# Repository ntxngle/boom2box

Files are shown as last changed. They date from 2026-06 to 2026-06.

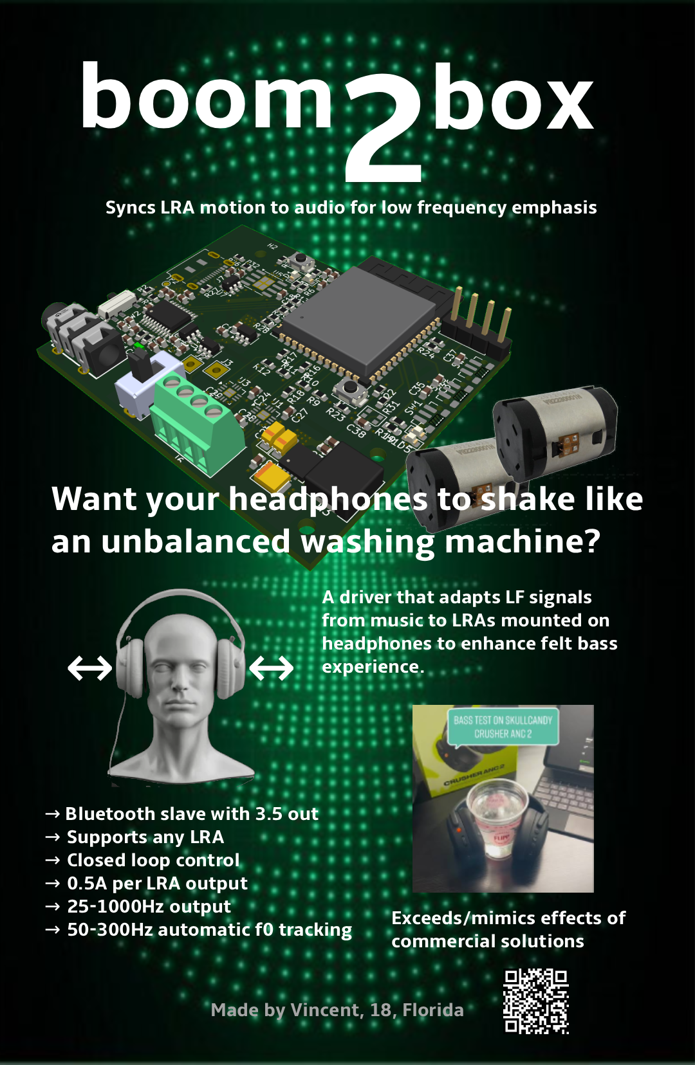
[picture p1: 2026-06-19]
docs/mzine.png

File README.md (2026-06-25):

# boom2box
## What and Why

A driver that adapts LF signals from music to LRAs mounted on headphones to enhance felt bass experience. It does this with a bunch of QoL features like leds, neopixel, switches, audio jack for lantency free experience.

In addition, the LRAs can be mounted to not only headphones: shaking a table or chair can also produce excellent results.

This is to replicate the feeling of having high power speakers which I can neither afford nor run. I always enjoy bass in music, and this project should hopefully replicate this experience at minimal cost (and minimal noise to peers). A few years ago a friend showed me his headphones and I was surprised to feel that they shook like crazy. This same geek blasted shadow money wizard gang at the crisp 6AM on the bus, so I figure he must know his music. Fast forward to a few months ago, I put some terribly old desktop speakers on my desk and spent very valuable time (in lieu of studying for linear: I now have an F) on maximizing bass output. Obviously to my disappointment I didn't feel the chest thumping explosions found only in brazilian car modifier demonstrations, it did vibrate my desk a little in the right conditions. A suprisingingly bass-like experience. Thus, after finishing my other fallout project, I set out to replicate that feeling in the most intense way. While i couldn't mount double digit diameter subwoofers in my obviously homework filled drawers, I figured I could cheat by generating the vibrations directly.

## Tuff photos

Since the project isn't tuff I don't have tuff photos. Here are some unrelated photos.








## How it works
A DSP grabs low end of incoming audio, does some normalization (or not) and sends waveform to LRA driver.

These LRA drivers are the jewel of the project: automatic f_0 tracking, closed loop, etc etc read the zine. They are the ones responsible for driving the huge 15$ 3.5G thumpers that I plan to connect to them: another versatility of this project is that other LRAs work. Anything from 10mm aliexpress buzzers to massive rectangular theater grade shakers (3Vrms, 1/2 amp max) will work identically (other than f0: DSP should be retuned to pitch bass up or down closer to f0 for maximum amplitude.

To avoid delay between audio and motion, a headphone jack is included. This way I can control audio out to motion, to solve potential (and variable) desyncs. It also makes for a great way to turn wired over-ears (the target of this project) into wireless skull shakers.

## BOM
|name |quantity|cost |link |
|---|---|-----|---|
|PCB |1 |76.32|gerbers in this repo |
|LRA VG2230001H |2 |15.66|https://www.digikey.com/en/products/detail/vybronics-inc/VG2230001H/16719289|
|1c LiPo >500mAh|1 |5 |tear one out of genuinely anything |
|Case |1 |~2 |Simple ahh 3d printed case costs like 10 cents in filament |
|total |1 |98.98| |

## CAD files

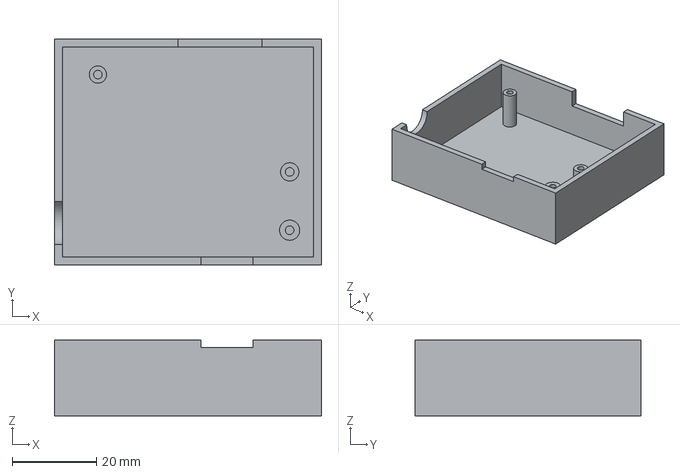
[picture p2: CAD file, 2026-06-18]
mechanical/case.step
63.5 x 53.8 x 18.0 mm

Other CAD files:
mechanical/case.FCStd

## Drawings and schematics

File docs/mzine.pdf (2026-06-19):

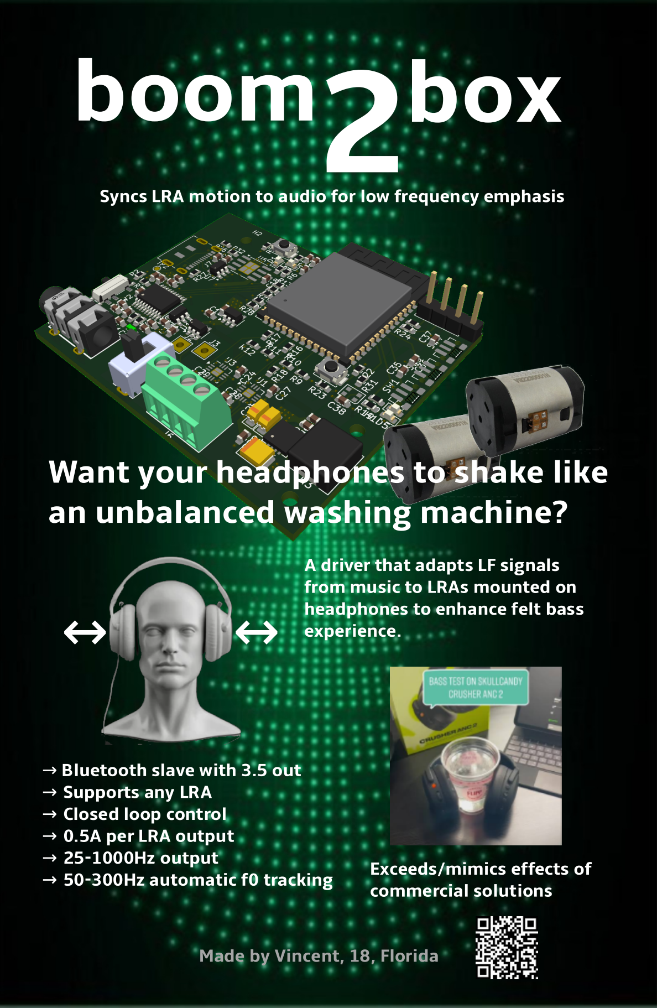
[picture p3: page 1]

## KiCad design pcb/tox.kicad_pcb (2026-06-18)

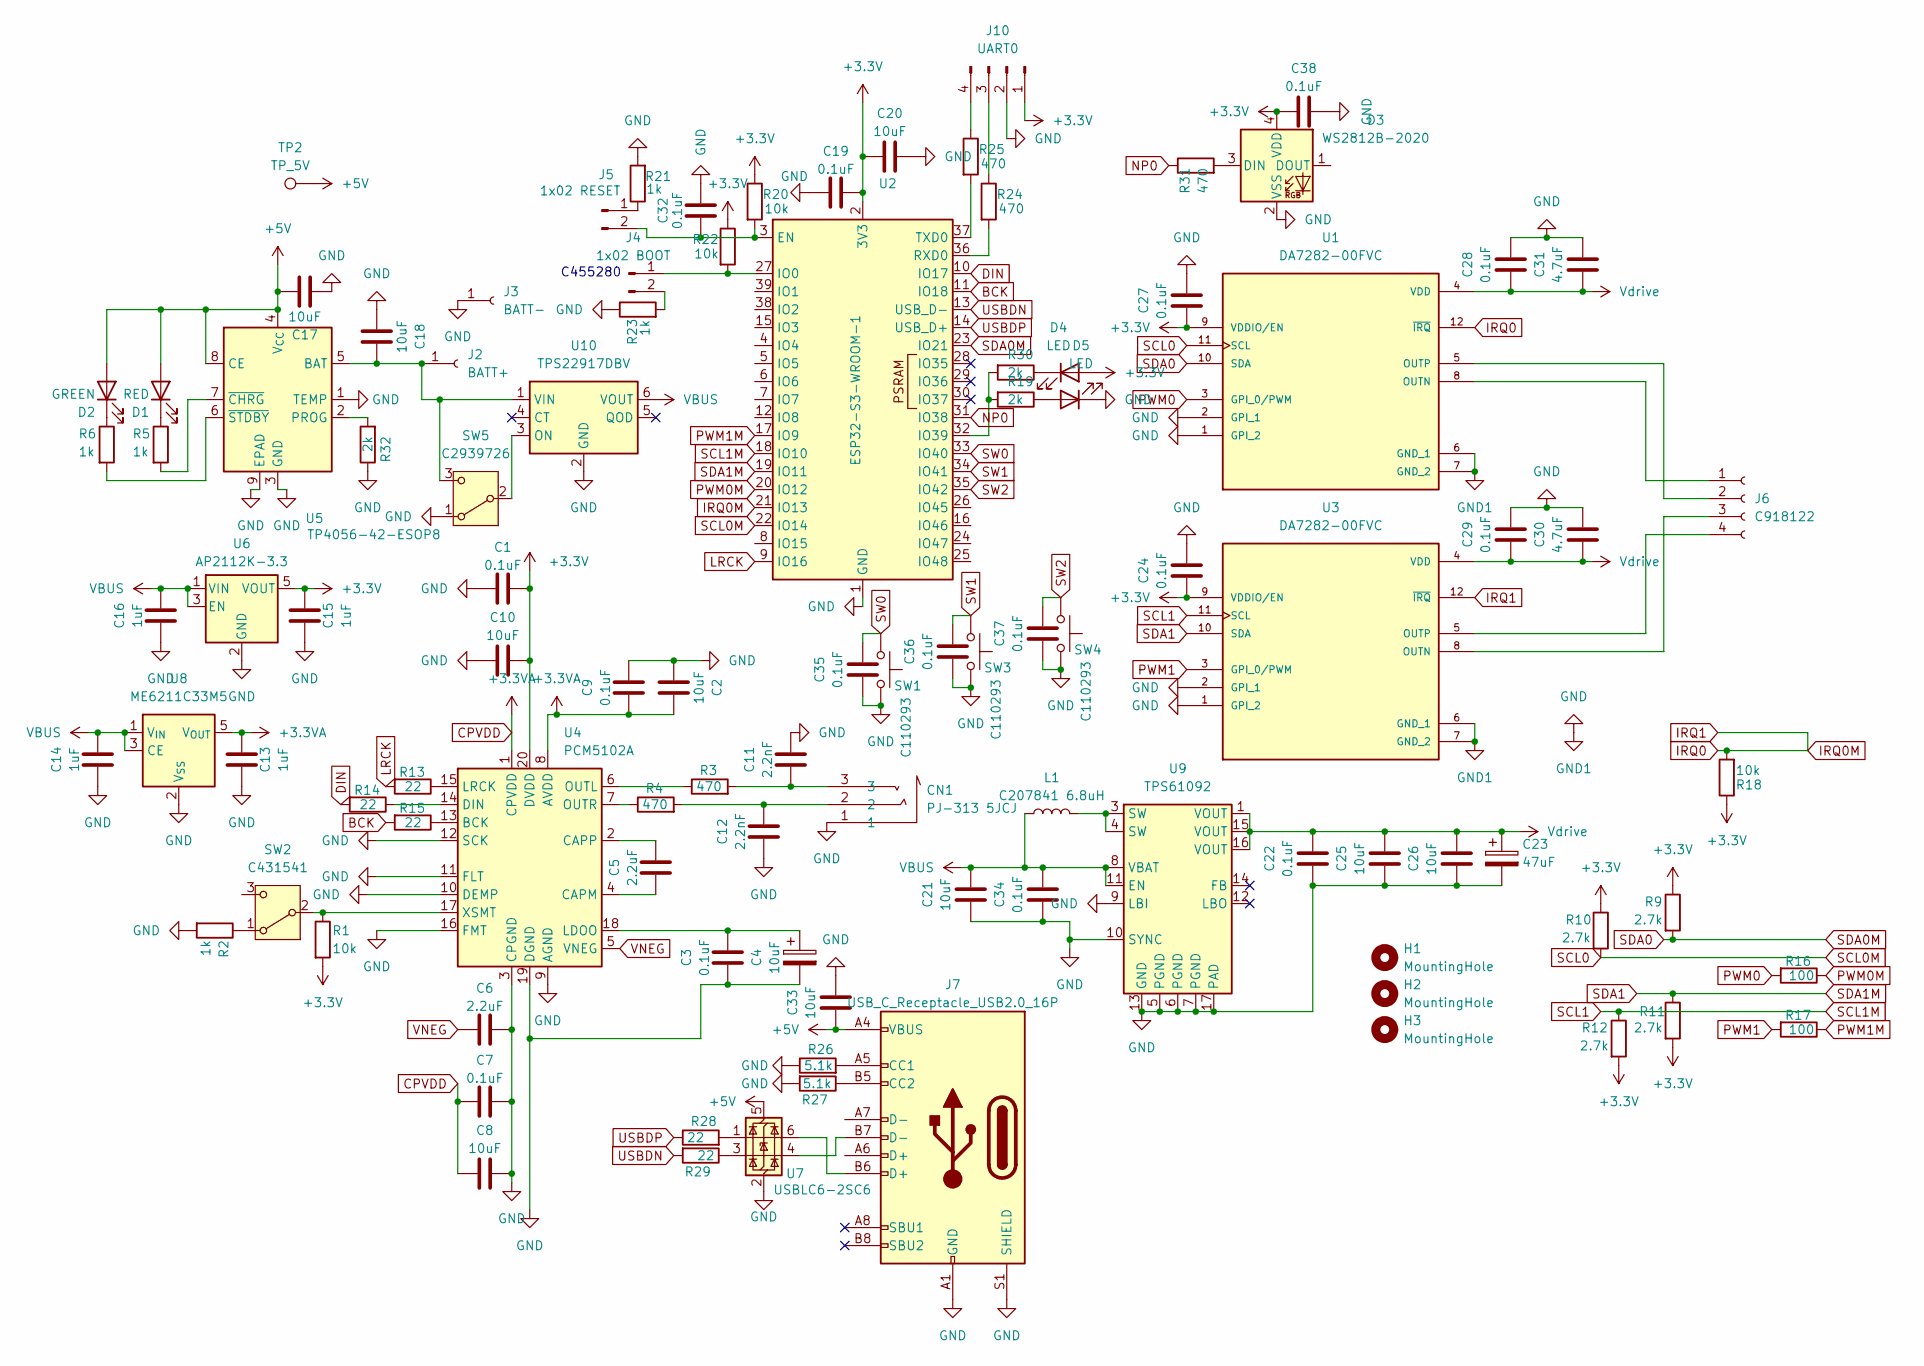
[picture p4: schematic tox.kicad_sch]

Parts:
C1, C3, C7, C9, C19, C22, C24, C27, C28, C29, C32, C34, C35, C36, C37, C38: 0.1uF; C_0603_1608Metric
C2, C4, C8, C10, C17, C18, C20, C21, C33: 10uF; C_0603_1608Metric
C5, C6: 2.2uF; C_0603_1608Metric
C11, C12: 2.2nF; C_0603_1608Metric
C13, C14, C15, C16: 1uF; C_0603_1608Metric
C23: 47uF; CP_EIA-3528-12_Kemet-T
C25, C26: 10uF; CP_EIA-3216-18_Kemet-A
C30, C31: 4.7uF; C_0603_1608Metric
CN1: PJ-313 5JCJ; AUDIO-TH_PJ-313_5JCJ; MPN PJ-313 5JCJ; LCSC Part C668607
D1: RED; LED_0603_1608Metric
D2: GREEN; LED_0603_1608Metric
D3: WS2812B-2020; LED_WS2812B-2020_PLCC4_2.0x2.0mm
D4, D5: LED; LED_0603_1608Metric
H1, H2, H3: MountingHole; MountingHole_2.1mm
J2: BATT+; TestPoint_THTPad_2.5x2.5mm_Drill1.2mm
J3: BATT-; TestPoint_THTPad_2.5x2.5mm_Drill1.2mm
J4: 1x02 BOOT; SW_Push_SPST_NO_Alps_SKRK
J5: 1x02 RESET; SW_Push_SPST_NO_Alps_SKRK
J6: C918122; CONN-TH_DB125-2.54-4P-GN
J7: USB_C_Receptacle_USB2.0_16P; USB_C_Receptacle_JAE_DX07S016JA1R1500
J10: UART0; PinHeader_1x04_P2.54mm_Vertical
L1: C207841 6.8uH; L_AVX_LMLP07A7
R1, R18, R20, R22: 10k; R_0603_1608Metric
R2, R5, R6, R21, R23: 1k; R_0603_1608Metric
R3, R4, R24, R25, R31: 470; R_0603_1608Metric
R9, R10, R11, R12: 2.7k; R_0603_1608Metric
R13, R14, R15, R28, R29: 22; R_0603_1608Metric
R16, R17: 100; R_0603_1608Metric
R19, R30, R32: 2k; R_0603_1608Metric
R26, R27: 5.1k; R_0603_1608Metric
SW1, SW3, SW4: C110293; SW_Push_1P1T-MP_NO_Horizontal_Alps_SKRTLAE010
SW2: C431541; SW_SPDT_PCM12
SW5: C2939726; SW_SS12D07VG4
TP2: TP_5V; TestPoint_Pad_D1.0mm
U1, U3: DA7282-00FVC; QFN-12-1EP_3x3mm_P0.5mm_EP1.45x1.45mm; PARTREV 3.1
U2: ESP32-S3-WROOM-1
U4: PCM5102A; TSSOP-20_4.4x6.5mm_P0.65mm
U5: TP4056-42-ESOP8; SOIC-8-1EP_3.9x4.9mm_P1.27mm_EP2.41x3.3mm
U6: AP2112K-3.3; SOT-23-5
U7: USBLC6-2SC6; SOT-23-6
U8: ME6211C33M5; SOT-23-5
U9: TPS61092; Texas_RSA_VQFN-16-1EP_4x4mm_P0.65mm_EP2.7x2.7mm
U10: TPS22917DBV; SOT-23-6

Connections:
+3.3V: C1.2, C10.1, C15.1, C19.2, C20.2, C24.2, C27.2, C38.2, D3.4 (VDD), D4.2 (A), J10.1, R1.2, R9.1, R10.1, R11.2, R12.2, R18.1, R20.1, R22.1, U1.9 (VDDIO/EN), U2.2 (3V3), U3.9 (VDDIO/EN), U4.20 (DVDD), U6.5 (VOUT)
+5V: C17.1, C33.2, D1.2 (A), D2.2 (A), J7.A4 (VBUS), J7.A9 (VBUS), J7.B4 (VBUS), J7.B9 (VBUS), TP2.1, U5.4 (V_{CC}), U5.8 (CE), U7.5 (VBUS)
BCK: R15.2, U2.11 (IO18)
CPVDD: C2.1, C7.1, C8.2, C9.1, C13.1, U4.1 (CPVDD), U4.8 (AVDD), U8.5 (V_{OUT})
DIN: R14.2, U2.10 (IO17)
GND: C1.1, C2.2, C3.1, C4.2, C6.2, C7.2, C8.1, C9.2, C10.2, C11.2, C12.1, C13.2, C14.1, C15.2, C16.1, C17.2, C18.2, C19.1, C20.1, C21.2, C22.2, C23.2, C24.1, C25.2, C26.2, C27.1, C28.1, C29.1, C30.1, C31.1, C32.2, C33.1, C34.2, C35.2, C36.2, C37.2, C38.1, CN1.1, D3.2 (VSS), D5.1 (K), J3.1, J7.A1 (GND), J7.A12 (GND), J7.B1 (GND), J7.B12 (GND), J7.S1 (SHIELD), J10.2, R2.2, R21.2, R23.1, R26.1, R27.2, R32.1, SW1.2, SW3.2, SW4.2, SW5.1 (A), U1.1 (GPI_2), U1.2 (GPI_1), U1.6 (GND_1), U1.7 (GND_2), U2.1 (GND), U2.40 (GND), U2.41 (GND), U3.1 (GPI_2), U3.2 (GPI_1), U3.6 (GND_1), U3.7 (GND_2), U4.3 (CPGND), U4.9 (AGND), U4.10 (DEMP), U4.11 (FLT), U4.12 (SCK), U4.16 (FMT), U4.19 (DGND), U5.1 (TEMP), U5.3 (GND), U5.9 (EPAD), U6.2 (GND), U7.2 (GND), U8.2 (V_{SS}), U9.5 (PGND), U9.6 (PGND), U9.7 (PGND), U9.9 (LBI), U9.10 (SYNC), U9.13 (GND), U9.17 (PAD), U10.2 (GND); also elsewhere on the board
IRQ0: R18.2, U1.12 (~IRQ), U2.21 (IO13), U3.12 (~IRQ)
LRCK: R13.2, U2.9 (IO16)
NP0: R31.1, U2.31 (IO38)
unnamed: C11.1, CN1.3, R3.2
unnamed: C12.2, CN1.2, R4.2
unnamed: D1.1 (K), R5.1
unnamed: D2.1 (K), R6.1
unnamed: D3.3 (DIN), R31.2
unnamed: D4.1 (K), R30.1
unnamed: D5.2 (A), R19.1
unnamed 16: C18.1, J2.1, SW5.3 (C), U5.5 (BAT), U10.1 (VIN); also elsewhere on the board
unnamed: J4.1, R22.2, U2.27 (IO0)
unnamed: J4.2, R23.2
unnamed: J5.1, R21.1
unnamed: C32.1, J5.2, R20.2, U2.3 (EN)
unnamed: J6.1, U1.8 (OUTN)
unnamed: J6.2, U1.5 (OUTP)
unnamed: J6.3, U3.8 (OUTN)
unnamed: J6.4, U3.5 (OUTP)
unnamed: J7.A5 (CC1), R26.2
unnamed: J7.B5 (CC2), R27.1
unnamed: J7.B6 (D+), U7.6 (I/O1)
unnamed: J7.B7 (D-), U7.4 (I/O2)
unnamed: J10.3, R24.1
unnamed: J10.4, R25.1
unnamed: L1.2, U9.3 (SW), U9.4 (SW)
unnamed: R28.2, U7.1 (I/O1)
unnamed: R29.1, U7.3 (I/O2)
unnamed: R2.1, SW2.1 (A)
unnamed: R1.1, SW2.2 (B), U4.17 (XSMT)
unnamed: SW5.2 (B), U10.3 (ON)
unnamed: R19.2, R30.2, U2.32 (IO39)
unnamed: R24.2, U2.36 (RXD0)
unnamed: R25.2, U2.37 (TXD0)
unnamed: R15.1, U4.13 (BCK)
unnamed: C5.1, U4.4 (CAPM)
unnamed: C5.2, U4.2 (CAPP)
unnamed: R14.1, U4.14 (DIN)
unnamed: C3.2, C4.1, U4.18 (LDOO)
unnamed: R13.1, U4.15 (LRCK)
unnamed: R3.1, U4.6 (OUTL)
unnamed: R4.1, U4.7 (OUTR)
unnamed: R32.2, U5.2 (PROG)
unnamed: R5.2, U5.7 (~CHRG)
unnamed: R6.2, U5.6 (~STDBY)
PWM0: R16.2, U1.3 (GPI_0/PWM)
PWM0M: R16.1, U2.20 (IO12)
PWM1: R17.2, U3.3 (GPI_0/PWM)
PWM1M: R17.1, U2.17 (IO9)
SCL0: R10.2, U1.11 (SCL), U2.22 (IO14)
SCL1: R12.1, U2.18 (IO10), U3.11 (SCL)
SDA0: R9.2, U1.10 (SDA), U2.23 (IO21)
SDA1: R11.1, U2.19 (IO11), U3.10 (SDA)
SW0: C35.1, SW1.1, U2.33 (IO40)
SW1: C36.1, SW3.1, U2.34 (IO41)
SW2: C37.1, SW4.1, U2.35 (IO42)
USBDN: R29.2, U2.13 (USB_D-)
USBDP: R28.1, U2.14 (USB_D+)
VBUS: C14.2, C16.2, C21.1, C34.1, L1.1, U6.1 (VIN), U6.3 (EN), U8.1 (V_{IN}), U8.3 (CE), U9.8 (VBAT), U9.11 (EN), U10.6 (VOUT)
VNEG: C6.1, U4.5 (VNEG)
Vdrive: C22.1, C23.1, C25.1, C26.1, C28.2, C29.2, C30.2, C31.2, U1.4 (VDD), U3.4 (VDD), U9.1 (VOUT), U9.15 (VOUT), U9.16 (VOUT)

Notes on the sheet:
C455280

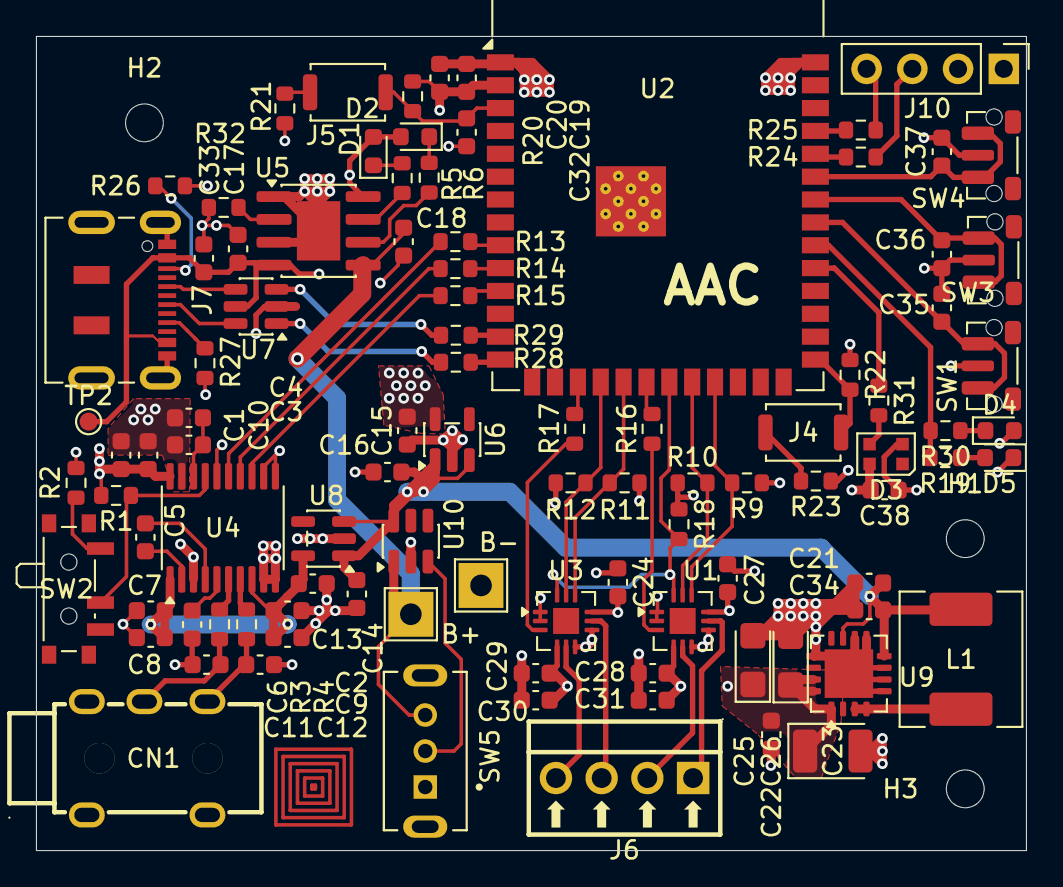
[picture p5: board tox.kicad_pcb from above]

Board: 4 copper layers, 55.0 x 45.2 mm, 101 parts (0 on the bottom side), 67 nets.

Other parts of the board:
B+: BATT+; TestPoint_THTPad_2.5x2.5mm_Drill1.2mm
B-: BATT-; TestPoint_THTPad_2.5x2.5mm_Drill1.2mm

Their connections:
GND: B-.1; also elsewhere on the board
unnamed 16: B+.1; also elsewhere on the board

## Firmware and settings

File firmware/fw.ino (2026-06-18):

//complete larp

#include "AudioTools.h"
#include "BluetoothA2DPSink.h"

#define I2S_BCLK      18
#define I2S_LRCK      16
#define I2S_DATA      17
#define HAPTIC_GPIO_1 12
#define HAPTIC_GPIO_2 9

I2SStream i2sOutput;
MultiOutput splitter;
BiquadFilter lowPassFilter;
FilteredStream<int16_t, int16_t> filteredI2S(i2sOutput, lowPassFilter); 

class HapticOutput : public AudioOutput{
public:
    bool begin(AudioInfo info) override { return true; }
    size_t write(const uint8_t* data, size_t bytes) override {
        int16_t* samples = (int16_t*)data;
        size_t count = bytes / 2;
        
        for (size_t i = 0; i < count; i += 2) {
            int16_t currentSample = samples[i]; 
            
            uint16_t magnitude = abs(currentSample);
            
            analogWrite(HAPTIC_GPIO_1, magnitude >> 8);
            analogWrite(HAPTIC_GPIO_2, magnitude >> 8);
        }
        return bytes;
    }
};

HapticOutput hapticStream;
BluetoothA2DPSink a2dp_sink;

void setup(){
    Serial.begin(115200);

    auto i2sConfig = i2sOutput.defaultConfig(TX_MODE);
    i2sConfig.pin_bck = I2S_BCLK;
    i2sConfig.pin_ws = I2S_LRCK;
    i2sConfig.pin_data = I2S_DATA;
    i2sConfig.sample_rate = 44100;
    i2sConfig.bits_per_sample = 16;
    i2sOutput.begin(i2sConfig);

  auto filterConfig = lowPassFilter.defaultConfig();
    filterConfig.cutoff_frequency = 150; 
    filterConfig.sample_rate = 44100;
    lowPassFilter.begin(filterConfig);
    filteredI2S.begin();
    splitter.add(filteredI2S);
    splitter.add(hapticStream);

    a2dp_sink.set_stream(splitter);
    a2dp_sink.start("boom2box");
}

void loop(){
    delay(10); 
}
